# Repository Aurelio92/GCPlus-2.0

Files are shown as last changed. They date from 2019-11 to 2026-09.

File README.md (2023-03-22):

# GC+ - What is it?
GC+ is a custom board that acts as a Gamecube controller with an upgradable firmware and custom features.
Video reference: https://www.youtube.com/watch?v=MTG2iqWmXx4

# What's new in version 2.0?
* Firmware completely written in C
* Complete controller functionality, including analog triggers and rumble
* Hardware emulation of the GC controller protocol
* Includes a rumble motor driver that supports both LRA and ERM rumble motors
* Additional Z2/ZL button to be used as an extra input for the BT emulation hack
* Compatible with 3DS sliders/Switch sticks without an external converter
* Configurable via homebrew with customizations including:
    * Remappable buttons (except triggers) (via PMv2, coming soon!)
    * Configurable triggers mode between digital and analog, allowing to use both standard triggers and dual---action tacts
    * Completely reconfigurable sticks, both in terms of ranges, and relocation
    * A new deadzone mode allowing for smooth transition across the center of the sticks
* Completely upgradeable!

# How to make one?
Eagle files are available in the Hardware folder. Use them to order PCBs from your favourite manufacturer.

# Needed parts
A BOM is available in the Hardware folder

# How to compile it
GC+2.0 is split in two MPLAB IDE projects. All that you need to do is open GCPlus2.0_Bootloader.X in MPLAB IDE and compile it. GCPlus2.0_Bootloader loads GCPlus2.0 internally. This means that when you compile the bootloader, an unified hex file containing both the bootloader and the main payload firmware. The main firmware project is configured to use a different memory region to avoid overlaps with the bootloader.

# How to flash it
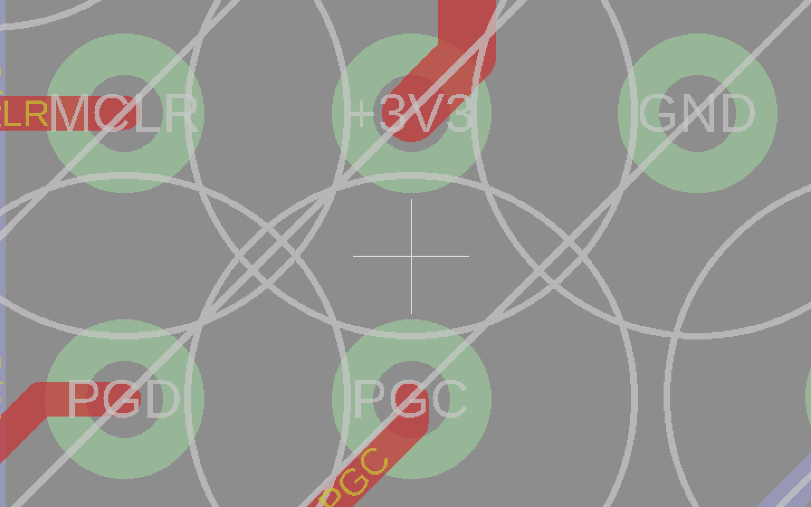
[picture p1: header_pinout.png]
picture alt
Markup : 
Flash GC+2.0.hex with MPLAB IPE (http://microchip.wikidot.com/ipe:installation) and a PICKIT v3 (or above).
Use the above pinout to wire up GC+2.0 to your PICKIT.

# Contacts
Please if you have any questions or if you want to implement new features reach out to me (Aurelio) on BitBuilt.net forums or our Discord server at https://discordapp.com/invite/uwT2AC.

If you use GC+2.0 and/or integrate it in your own project please do not forget to give credits where due and link to this repository.

# License

MIT License

Copyright (c) 2020 Aurelio Mannara

Permission is hereby granted, free of charge, to any person obtaining a copy
of this software and associated documentation files (the "Software"), to deal
in the Software without restriction, including without limitation the rights
to use, copy, modify, merge, publish, distribute, sublicense, and/or sell
copies of the Software, and to permit persons to whom the Software is
furnished to do so, subject to the following conditions:

The above copyright notice and this permission notice shall be included in all
copies or substantial portions of the Software.

THE SOFTWARE IS PROVIDED "AS IS", WITHOUT WARRANTY OF ANY KIND, EXPRESS OR
IMPLIED, INCLUDING BUT NOT LIMITED TO THE WARRANTIES OF MERCHANTABILITY,
FITNESS FOR A PARTICULAR PURPOSE AND NONINFRINGEMENT. IN NO EVENT SHALL THE
AUTHORS OR COPYRIGHT HOLDERS BE LIABLE FOR ANY CLAIM, DAMAGES OR OTHER
LIABILITY, WHETHER IN AN ACTION OF CONTRACT, TORT OR OTHERWISE, ARISING FROM,
OUT OF OR IN CONNECTION WITH THE SOFTWARE OR THE USE OR OTHER DEALINGS IN THE
SOFTWARE.E, ARISING FROM,
OUT OF OR IN CONNECTION WITH THE SOFTWARE OR THE USE OR OTHER DEALINGS IN THE
SOFTWARE.

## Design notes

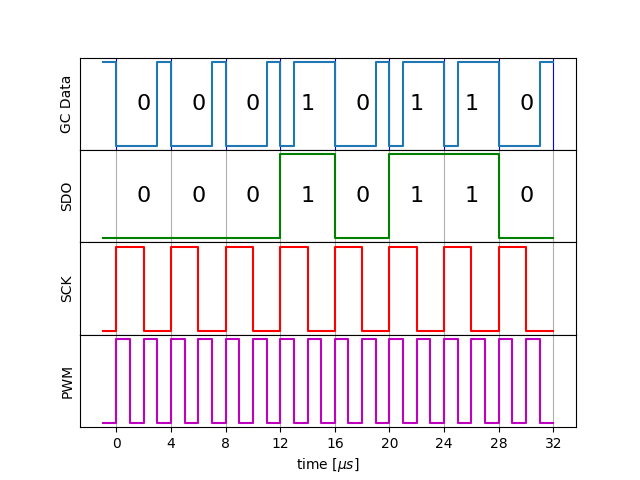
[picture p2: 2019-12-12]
gcplus2.png

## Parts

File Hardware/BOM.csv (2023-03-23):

Qty | Value | Device | Package | Parts | Description
3 | 0.1uF | C-EUC0402 | C0402 | C1, C2, C3 | CAPACITOR, European symbol
2 | 10kOhm | R-US_R0402 | R0402 | R1, R3 | RESISTOR, American symbol
1 | 100Ohm | R-US_R0402 | R0402 | R2 | RESISTOR, American symbol
1 | PIC18F25K42 | PIC18F25K42 | QFN-28 | U1
1 | DRV2603 | DRV2603 | WQFN-10 | U2

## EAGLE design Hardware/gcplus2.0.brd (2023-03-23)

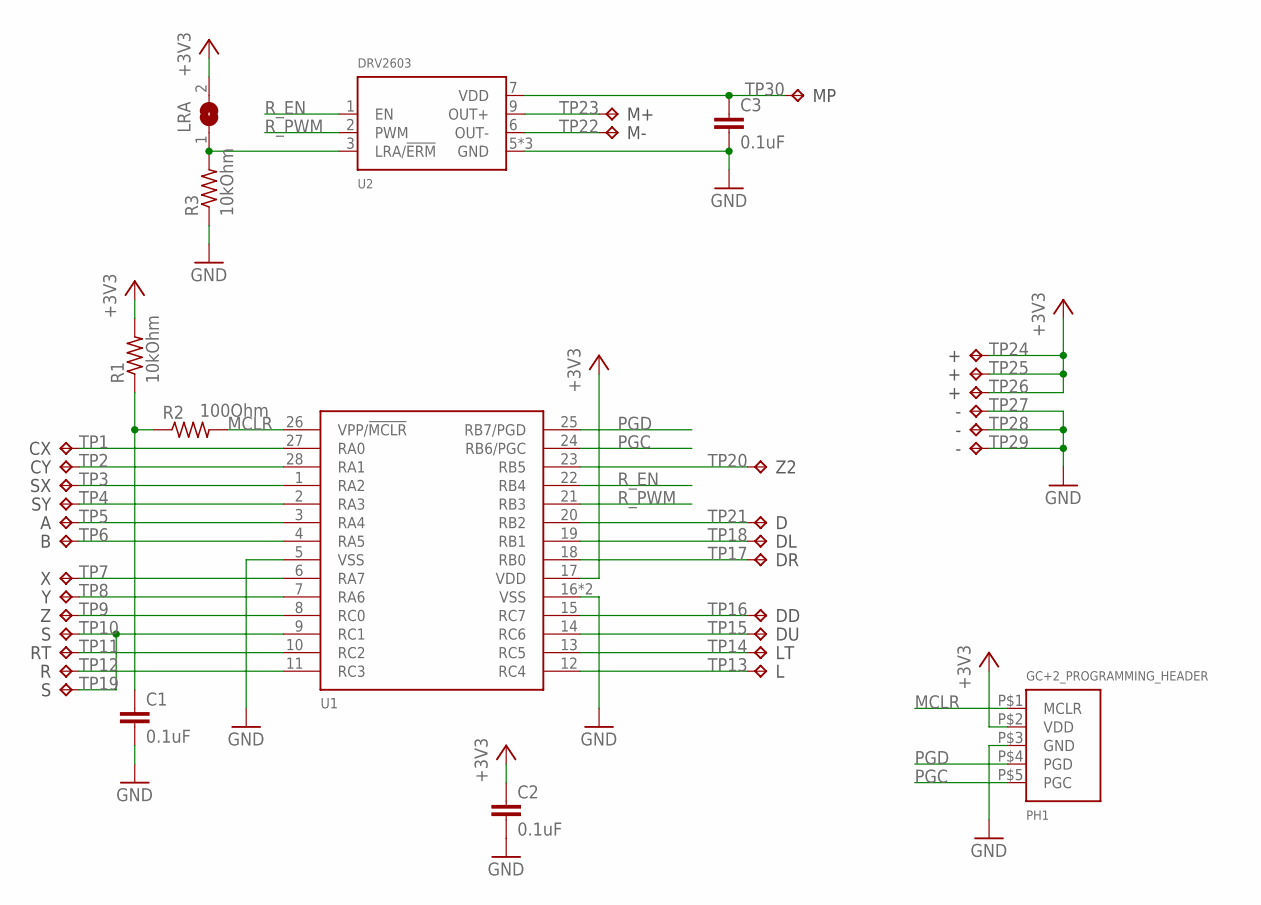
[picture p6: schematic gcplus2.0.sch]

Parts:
C1, C2, C3: 0.1uF; C0402
LRA: SJ
PH1: GC+2_PROGRAMMING_HEADER
R1, R3: 10kOhm; R0402
R2: 100Ohm; R0402
TP1, TP2, TP3, TP4, TP5, TP6, TP7, TP8, TP9, TP10, TP11, TP12, TP13, TP14, TP15, TP16, TP17, TP18, TP19, TP20, TP21, TP22, TP23, TP24, TP25, TP26, TP27, TP28, TP29, TP30: TPTP10SQ; TP10SQ
U1: PIC18F25K42; QFN-28
U2: DRV2603; WQFN-10

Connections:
+3V3: C2.1, LRA.2, PH1.P$2 (VDD), R1.2, TP24.TP, TP25.TP, TP26.TP, U1.17 (VDD)
GND: C1.2, C2.2, C3.2, PH1.P$3 (GND), R3.1, TP27.TP, TP28.TP, TP29.TP, U1.5 (VSS), U1.16 (VSS), U1.PAD (VSS), U2.5 (GND), U2.8 (GND), U2.10 (GND)
MCLR: PH1.P$1 (MCLR), R2.2, U1.26 (VPP/!MCLR)
MP: C3.1, TP30.TP, U2.7 (VDD)
unnamed: TP1.TP, U1.27 (RA0)
unnamed: TP2.TP, U1.28 (RA1)
unnamed: TP3.TP, U1.1 (RA2)
unnamed: TP4.TP, U1.2 (RA3)
unnamed: TP5.TP, U1.3 (RA4)
unnamed: TP6.TP, U1.4 (RA5)
unnamed: TP7.TP, U1.6 (RA7)
unnamed: TP8.TP, U1.7 (RA6)
unnamed: TP9.TP, U1.8 (RC0)
unnamed: LRA.1, R3.2, U2.3 (LRA/!ERM)
unnamed: TP10.TP, TP19.TP, U1.9 (RC1)
unnamed: TP11.TP, U1.10 (RC2)
unnamed: TP12.TP, U1.11 (RC3)
unnamed: TP14.TP, U1.13 (RC5)
unnamed: TP15.TP, U1.14 (RC6)
unnamed: TP16.TP, U1.15 (RC7)
unnamed: TP17.TP, U1.18 (RB0)
unnamed: TP18.TP, U1.19 (RB1)
unnamed: TP21.TP, U1.20 (RB2)
unnamed: TP23.TP, U2.9 (OUT+)
unnamed: TP22.TP, U2.6 (OUT-)
unnamed: TP20.TP, U1.23 (RB5)
unnamed: C1.1, R1.1, R2.1
unnamed: TP13.TP, U1.12 (RC4)
PGC: PH1.P$5 (PGC), U1.24 (RB6/PGC)
PGD: PH1.P$4 (PGD), U1.25 (RB7/PGD)
R_EN: U1.22 (RB4), U2.1 (EN)
R_PWM: U1.21 (RB3), U2.2 (PWM)

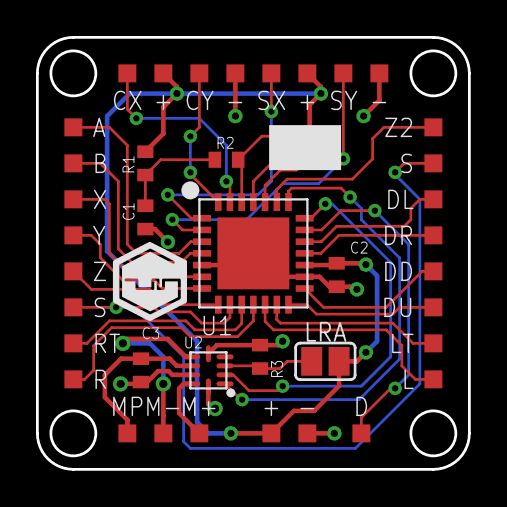
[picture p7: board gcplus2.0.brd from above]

Board: 2 copper layers, 24.0 x 24.0 mm, 40 parts (0 on the bottom side), 32 nets.

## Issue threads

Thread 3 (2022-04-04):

Usar potenciómetros xbox como gatitos L R

JackLine087, 2022-04-04:
Hola soy nuevo con esta placa GC Plus y quería hacer un proyecto de usar un control de Xbox clásico del primer control, mi idea es usar el gc plus como el cerebro del control sería como añadir un nuevo núcleo que remapearia los botones de la placa del control al gc plus eso es fácil solo soldando unos cables internos que no ocupan mayor espacio, y ejecutarlo como si fuera un control de gamecube no obstante, tengo una duda y es que los controles de xbox clássico en los gatillo (L R) no poseen botones sino que usa potenciómetros y queria saber como podría ejecutar estos potenciómetros como botones para el gc plus 🙏

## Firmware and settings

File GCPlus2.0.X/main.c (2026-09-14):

// CONFIG1L
#pragma config FEXTOSC = OFF    // External Oscillator Selection (Oscillator not enabled)
#pragma config RSTOSC = HFINTOSC_64MHZ// Reset Oscillator Selection (HFINTOSC with HFFRQ = 64 MHz and CDIV = 1:1)

// CONFIG1H
#pragma config CLKOUTEN = OFF   // Clock out Enable bit (CLKOUT function is disabled)
#pragma config PR1WAY = OFF     // PRLOCKED One-Way Set Enable bit (PRLOCK bit can be set and cleared repeatedly)
#pragma config CSWEN = ON       // Clock Switch Enable bit (Writing to NOSC and NDIV is allowed)
#pragma config FCMEN = ON       // Fail-Safe Clock Monitor Enable bit (Fail-Safe Clock Monitor enabled)

// CONFIG2L
#pragma config MCLRE = EXTMCLR  // MCLR Enable bit (If LVP = 0, MCLR pin is MCLR; If LVP = 1, RE3 pin function is MCLR )
#pragma config PWRTS = PWRT_OFF // Power-up timer selection bits (PWRT is disabled)
#pragma config MVECEN = OFF     // Multi-vector enable bit (Interrupt contoller does not use vector table to prioritze interrupts)
#pragma config IVT1WAY = OFF    // IVTLOCK bit One-way set enable bit (IVTLOCK bit can be cleared and set repeatedly)
#pragma config LPBOREN = OFF    // Low Power BOR Enable bit (ULPBOR disabled)
#pragma config BOREN = SBORDIS  // Brown-out Reset Enable bits (Brown-out Reset enabled , SBOREN bit is ignored)

// CONFIG2H
#pragma config BORV = VBOR_2P85 // Brown-out Reset Voltage Selection bits (Brown-out Reset Voltage (VBOR) set to 2.85V)
#pragma config ZCD = OFF        // ZCD Disable bit (ZCD disabled. ZCD can be enabled by setting the ZCDSEN bit of ZCDCON)
#pragma config PPS1WAY = OFF    // PPSLOCK bit One-Way Set Enable bit (PPSLOCK bit can be set and cleared repeatedly (subject to the unlock sequence))
#pragma config STVREN = ON      // Stack Full/Underflow Reset Enable bit (Stack full/underflow will cause Reset)
#pragma config DEBUG = OFF      // Debugger Enable bit (Background debugger disabled)
#pragma config XINST = OFF      // Extended Instruction Set Enable bit (Extended Instruction Set and Indexed Addressing Mode disabled)

// CONFIG3L
#pragma config WDTCPS = WDTCPS_12// WDT Period selection bits (Divider ratio 1:131072)
#pragma config WDTE = ON        // WDT operating mode (WDT enabled regardless of sleep)

// CONFIG3H
#pragma config WDTCWS = WDTCWS_7// WDT Window Select bits (window always open (100%); software control; keyed access not required)
#pragma config WDTCCS = LFINTOSC// WDT input clock selector (WDT reference clock is the 31.0 kHz LFINTOSC)

// CONFIG4L
#pragma config BBSIZE = BBSIZE_4096// Boot Block Size selection bits (Boot Block size is 4096 words)
#pragma config BBEN = ON       // Boot Block enable bit (Boot block enabled)
#pragma config SAFEN = ON       // Storage Area Flash enable bit (SAF enabled)
#pragma config WRTAPP = OFF     // Application Block write protection bit (Application Block not write protected)

// CONFIG4H
#pragma config WRTB = ON        // Configuration Register Write Protection bit (Configuration registers (300000-30000Bh) write-protected)
#pragma config WRTC = OFF       // Boot Block Write Protection bit (Boot Block (000000-0007FFh) not write-protected)
#pragma config WRTD = OFF       // Data EEPROM Write Protection bit (Data EEPROM not write-protected)
#pragma config WRTSAF = OFF     // SAF Write protection bit (SAF not Write Protected)
#pragma config LVP = ON         // Low Voltage Programming Enable bit (Low voltage programming enabled. MCLR/VPP pin function is MCLR. MCLRE configuration bit is ignored)

// CONFIG5L
#pragma config CP = OFF         // PFM and Data EEPROM Code Protection bit (PFM and Data EEPROM code protection disabled)

#include "main.h"

void main(void) {
    uint8_t i;
    uint8_t cmdLen = 0;
    char cmd[0x24];
    char msgAnswer[0x24];
    uint8_t gcpLocked = 1;
    uint16_t addr;

    //Bootloader buffer stuff
    uint8_t flashBuffer[64];
    uint8_t flashBufferIdx = 0;

    /*//Clock is already be set at 64MHz in the configuration register. This is useless
    // NOSC HFINTOSC; NDIV 1;
    OSCCON1 = 0x60;
    // CSWHOLD may proceed; SOSCPWR Low power;
    OSCCON3 = 0x00;
    // MFOEN disabled; LFOEN disabled; ADOEN disabled; SOSCEN disabled; EXTOEN disabled; HFOEN disabled;
    OSCEN = 0x00;
    // HFFRQ 64_MHz;
    OSCFRQ = 0x08;
    // TUN 0;
    OSCTUNE = 0x00;*/

    portsInit();

    //Read buttons for boot combos
    inButtons_t inBut;
    inBut.PORTA = PORTA;
    inBut.PORTB = PORTB;
    inBut.PORTC = PORTC;

    configInit();
    if (config.triggersMode == TRIG_MODE_ANALOG) {
        ANSELC |= 0x18; //Enable analog on triggers
        WPUC &= ~0x18; //Disable weak pullups on triggers
    }

    ADCInit(config.SXChan, config.SYChan, config.CXChan, config.CYChan);
    buttonsInit();
    SIInit();
    rumbleInit();
    //Restore configuration if X+Y+A are all pressed
    if (!inBut.X && !inBut.Y && !inBut.A) {
        configSetDefault();
        configFlashAll();
    }

    buttonsBuildLUTs();

    INTCON0 = 0x80; //Interrupts enabled with no priority

    while (1) {
        inBut.PORTA = PORTA;
        inBut.PORTB = PORTB;
        inBut.PORTC = PORTC;
        //If X+Y+Start are all pressed, don't reset the WDT
        if (inBut.X || inBut.Y || inBut.ST) {
            asm("clrwdt");
        }
        buttonsUpdate();
        cmdLen = SIGetCommand(cmd);

        if (cmdLen > 0) {
            switch(cmd[0]) {
                case GCP_CMD_LOCKUNLOCK:
                    if ((cmd[1] == 0x47) && (cmd[2] == 0x43) && (cmd[3] == 0x2B) && (cmd[4] == 0x32) && cmdLen == 5) {
                        gcpLocked = 0;
                    } else {
                        gcpLocked = 1;
                    }
                    msgAnswer[0] = GCP_ERR_NONE;
                    SISendMessage(msgAnswer, 1);
                break;

                case GCP_CMD_GETVER:
                    if (!gcpLocked) {
                        msgAnswer[0] = 0x02; //Payload
                        msgAnswer[1] = GCP2_VERSION & 0xFFUL;
                        msgAnswer[2] = (GCP2_VERSION >> 8) & 0xFF;
                        msgAnswer[3] = GCP2_HWVERSION & 0xFFUL;
                        msgAnswer[4] = (GCP2_HWVERSION >> 8) & 0xFF;
                        SISendMessage(msgAnswer, 5);
                    } else {
                        msgAnswer[0] = GCP_ERR_LOCKED;
                        SISendMessage(msgAnswer, 1);
                    }
                break;

                case GCP_CMD_WRITEEEPROM:
                    if (!gcpLocked) {
                        if (cmdLen > 3) {
                            addr = cmd[2];
                            addr = addr << 8;
                            addr |= cmd[1];
                            for (i = 3; i < cmdLen; i++) {
                                EEPROMWriteByte(addr++, cmd[i]);
                            }
                            msgAnswer[0] = GCP_ERR_NONE;
                            SISendMessage(msgAnswer, 1);
                        } else {
                            msgAnswer[0] = GCP_ERR_WRONGARG;
                            SISendMessage(msgAnswer, 1);
                        }
                    } else {
                        msgAnswer[0] = GCP_ERR_LOCKED;
                        SISendMessage(msgAnswer, 1);
                    }
                break;

                case GCP_CMD_READEEPROM:
                    if (!gcpLocked) {
                        if (cmdLen == 4) {
                            addr = cmd[2];
                            addr = addr << 8;
                            addr |= cmd[1];
                            uint8_t len = cmd[3];
                            if (len == 0) {
                                msgAnswer[0] = GCP_ERR_WRONGARG;
                                SISendMessage(msgAnswer, 1);
                            } else {
                                msgAnswer[0] = GCP_ERR_NONE;
                                for (i = 0; i < len && i < 0x20; i++) {
                                    msgAnswer[i + 1] = EEPROMReadByte(addr++);
                                }
                                SISendMessage(msgAnswer, len + 1);
                            }
                        } else {
                            msgAnswer[0] = GCP_ERR_WRONGARG;
                            SISendMessage(msgAnswer, 1);
                        }
                    } else {
                        msgAnswer[0] = GCP_ERR_LOCKED;
                        SISendMessage(msgAnswer, 1);
                    }
                break;

                case GCP_CMD_RESET:
                    asm("reset");
                break;

                case GCP_CMD_BOOTBL:
                    if (!gcpLocked) {
                        msgAnswer[0] = GCP_ERR_NONE;
                        SISendMessage(msgAnswer, 1);
                        bootBootloader();
                    } else {
                        msgAnswer[0] = GCP_ERR_LOCKED;
                        SISendMessage(msgAnswer, 1);
                    }
                break;

                case GCP_CMD_SETMAPBYTE0:
                    if (!gcpLocked) {
                        if (cmdLen == (N_BUTTONS + 1)) {
                            buttonsSetMapByte0(&cmd[1]);
                            msgAnswer[0] = GCP_ERR_NONE;
                            SISendMessage(msgAnswer, 1);
                        } else {
                            msgAnswer[0] = GCP_ERR_WRONGARG;
                            SISendMessage(msgAnswer, 1);
                        }
                    } else {
                        msgAnswer[0] = GCP_ERR_LOCKED;
                        SISendMessage(msgAnswer, 1);
                    }
                break;

                case GCP_CMD_SETMAPBYTE1:
                    if (!gcpLocked) {
                        if (cmdLen == (N_BUTTONS + 1)) {
                            buttonsSetMapByte1(&cmd[1]);
                            msgAnswer[0] = GCP_ERR_NONE;
                            SISendMessage(msgAnswer, 1);
                        } else {
                            msgAnswer[0] = GCP_ERR_WRONGARG;
                            SISendMessage(msgAnswer, 1);
                        }
                    } else {
                        msgAnswer[0] = GCP_ERR_LOCKED;
                        SISendMessage(msgAnswer, 1);
                    }
                break;

                case GCP_CMD_GETMAPBYTE0:
                    if (!gcpLocked) {
                        uint8_t* btnMsg = buttonsGetMapByte0();
                        msgAnswer[0] = GCP_ERR_NONE;
                        for (i = 0; i < N_BUTTONS; i++) {
                            msgAnswer[i + 1] = btnMsg[i];
                        }
                        SISendMessage(msgAnswer, N_BUTTONS + 1);
                    } else {
                        msgAnswer[0] = GCP_ERR_LOCKED;
                        SISendMessage(msgAnswer, 1);
                    }
                break;

                case GCP_CMD_GETMAPBYTE1:
                    if (!gcpLocked) {
                        uint8_t* btnMsg = buttonsGetMapByte1();
                        msgAnswer[0] = GCP_ERR_NONE;
                        for (i = 0; i < N_BUTTONS; i++) {
                            msgAnswer[i + 1] = btnMsg[i];
                        }
                        SISendMessage(msgAnswer, N_BUTTONS + 1);
                    } else {
                        msgAnswer[0] = GCP_ERR_LOCKED;
                        SISendMessage(msgAnswer, 1);
                    }
                break;

                case GCP_CMD_REBUILDLUT:
                    if (!gcpLocked) {
                        buttonsBuildLUTs();
                        msgAnswer[0] = GCP_ERR_NONE;
                        SISendMessage(msgAnswer, 1);
                    } else {
                        msgAnswer[0] = GCP_ERR_LOCKED;
                        SISendMessage(msgAnswer, 1);
                    }
                break;

                default: //Unknown command
                    SIClear();
                break;
            }
        }
    }

    return;
}

//Commands answered at their stop bit. Called from the interrupt handler
static uint8_t idAnswer[3] = {0x09, 0x00, 0x03};
static uint8_t originAnswer[10] = {0x00, 0x80, 0x80, 0x80, 0x80, 0x80, 0x00, 0x00, 0x00, 0x00};

uint8_t directCommandLength(uint8_t cmd) {
    switch(cmd) {
        case SI_CMD_ID:
        case SI_CMD_RESET:
        case SI_CMD_ORIGINS:
            return 1;

        case SI_CMD_POLL:
        case SI_CMD_CALIB:
            return 3;

        default: //Not answered from the interrupt handler. Handled by the main loop after the bus timeout
            return 0;
    }
}

void directCommandAnswer(uint8_t* cmd) {
    switch(cmd[0]) {
        case SI_CMD_ID:
        case SI_CMD_RESET:
            SISendMessage(idAnswer, 3);
        break;

        case SI_CMD_POLL:
            //Handle rumble
            switch (cmd[2]) {
                case 1:
                    rumbleSpin(config.rumbleIntensity);
                break;

                case 2:
                    rumbleBrake();
                break;

                default:
                    rumbleStop();
                break;
            }
            //Answer
            SISendMessage(buttonsGetMessage(cmd[1], config.triggersMode), 8);
        break;

        case SI_CMD_ORIGINS:
        case SI_CMD_CALIB:
            SISendMessage(originAnswer, 10);
        break;
    }
}

void portsInit(void) {
    //Stop interrupts
    bool state = (unsigned char)GIE;
    GIE = 0;
    PPSLOCK = 0x55;
    PPSLOCK = 0xAA;
    PPSLOCKbits.PPSLOCKED = 0x00; //Unlock PPS

    //Data line wired to RB2
    //Reception
    T6INPPS = 0x0A; //RB2 to T6INPPS. Used as reset trigger
    SMT1SIGPPS = 0x0A; //RB2

    //Transmission
    RB2PPS = 0x04; //CLC4 to RB2

    //Rumble PWM
    RB3PPS = 0x09; //CCP1

    PPSLOCK = 0x55;
    PPSLOCK = 0xAA;
    PPSLOCKbits.PPSLOCKED = 0x01; //Lock PPS
    GIE = state; //Restore interrupts

    LATB = 0xEF;

    //Bootloader won't emulate analog triggers
    TRISA = 0xFF;
    TRISB = 0xE7;
    TRISC = 0xFF;
    ANSELA = 0x0F;
    ANSELB = 0x00;
    ANSELC = 0x00;
    WPUA = 0xF0;
    WPUB = 0x27;
    WPUC = 0xFF;
    ODCONA = 0x00;
    ODCONB = 0x04;
    ODCONC = 0x00;
}

void bootBootloader(void) {
    INTCON0 = 0x00; //Disable interrupts
    NCO1ACCL = 0x01;
    STKPTR = 0x00; //Clean up stack
    IVTLOCK = 0x55;
    IVTLOCK = 0xAA;
    IVTLOCK = 0;
    IVTLOCKED = 0;
    IVTBASE = 8; //Set interrupt base address
    IVTLOCK = 0x55;
    IVTLOCK = 0xAA;
    IVTLOCK = 1;
    IVTLOCKED = 1;
    //Jump to bootloader
    PCLATU = 0x00;
    PCLATH = 0x00;
    PCL = 0x00;
}

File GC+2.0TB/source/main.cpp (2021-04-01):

#include <stdio.h>
#include <stdlib.h>
#include <string.h>
#include <gccore.h>
#include <ogc/lwp_watchdog.h>
#include <ogc/machine/processor.h>
#include <wiiuse/wpad.h>
#include <ogc/ipc.h>
#include <fat.h>
#include <math.h>
#include <string>
#include <list>

#include "gpio.h"
#include "i2c.h"
#include "gcplus.h"

static void *xfb = NULL;
static GXRModeObj *rmode = NULL;

#define AVE_ADDR (0x70 << 1)

void startTest();
void padWait(int* held);
void printButtons(int held);
void testStickAxis(int ax);

std::list<std::string> errorList;

//---------------------------------------------------------------------------------
int main(int argc, char **argv) {
//---------------------------------------------------------------------------------

	// Initialise the video system
	VIDEO_Init();
	PAD_Init();
	WPAD_Init();

	// Obtain the preferred video mode from the system
	// This will correspond to the settings in the Wii menu
	rmode = VIDEO_GetPreferredMode(NULL);

	// Allocate memory for the display in the uncached region
	xfb = MEM_K0_TO_K1(SYS_AllocateFramebuffer(rmode));

	// Initialise the console, required for printf
	console_init(xfb,20,20,rmode->fbWidth,rmode->xfbHeight,rmode->fbWidth*VI_DISPLAY_PIX_SZ);

	// Set up the video registers with the chosen mode
	VIDEO_Configure(rmode);

	// Tell the video hardware where our display memory is
	VIDEO_SetNextFramebuffer(xfb);

	// Make the display visible
	VIDEO_SetBlack(FALSE);

	// Flush the video register changes to the hardware
	VIDEO_Flush();

	// Wait for Video setup to complete
	VIDEO_WaitVSync();
	if(rmode->viTVMode&VI_NON_INTERLACE) VIDEO_WaitVSync();

	int col, row;
	CON_GetPosition(&col, &row);

	u8 error;

	i2c_init();
	printf("\n\n");
	i2c_stop();

	for (int i = 0; i < 127; i++)
	{
		i2c_start();
		if (i2c_sendByte(i << 1))
		{
			printf("Found device on address: %02X\n", i);
		}
		i2c_stop();
	}

	printf("SI type: %08X\n", SI_GetType(0));
	printf("Press A on the Wiimote to start the test\n");
	while(1) {
		PAD_ScanPads();
		WPAD_ScanPads();


		int down = WPAD_ButtonsDown(0);
		if (down & WPAD_BUTTON_HOME) exit(0);
		if (down & WPAD_BUTTON_A) startTest();

		int held = PAD_ButtonsHeld(0);

		/*if (ticks_to_millisecs(gettime() - now) > 1000) {
			regVal = ~regVal;
			i2c_write8(0x40, 0x01, regVal, &error);
			now = gettime();
		}

		printf("\x1b[5;0H%08X %02X", held, regVal);*/

		// Wait for the next frame
		VIDEO_WaitVSync();
	}

	return 0;
}

void padWait(int* held) {
	u64 now = gettime();
	while (ticks_to_millisecs(gettime() - now) < 200) {
		PAD_ScanPads();
	}
	if (held != NULL) *held = PAD_ButtonsHeld(0);
}

void printButtons(int held) {
	if (held & PAD_BUTTON_A) printf("A ");
	if (held & PAD_BUTTON_B) printf("B ");
	if (held & PAD_BUTTON_X) printf("X ");
	if (held & PAD_BUTTON_Y) printf("Y ");
	if (held & PAD_TRIGGER_Z) printf("Z ");
	if (held & PAD_TRIGGER_R) printf("RT ");
	if (held & PAD_TRIGGER_L) printf("LT ");
	if (held & PAD_BUTTON_START) printf("START ");
	if (held & PAD_BUTTON_LEFT) printf("LEFT ");
	if (held & PAD_BUTTON_RIGHT) printf("RIGHT ");
	if (held & PAD_BUTTON_DOWN) printf("DOWN ");
	if (held & PAD_BUTTON_UP) printf("UP ");
	if (PAD_StickX(0)) printf("SX(%d) ", PAD_StickX(0));
	if (PAD_StickY(0)) printf("SY(%d) ", PAD_StickY(0));
	if (PAD_SubStickX(0)) printf("CX(%d) ", PAD_SubStickX(0));
	if (PAD_SubStickY(0)) printf("CY(%d) ", PAD_SubStickY(0));
	if (PAD_TriggerL(0)) printf("L(%u) ", PAD_TriggerL(0));
	if (PAD_TriggerR(0)) printf("R(%u) ", PAD_TriggerR(0));
}

void printButtonsToString(int held, char* str) {
	if (held & PAD_BUTTON_A) sprintf(str, "%sA ", str);
	if (held & PAD_BUTTON_B) sprintf(str, "%sB ", str);
	if (held & PAD_BUTTON_X) sprintf(str, "%sX ", str);
	if (held & PAD_BUTTON_Y) sprintf(str, "%sY ", str);
	if (held & PAD_TRIGGER_Z) sprintf(str, "%sZ ", str);
	if (held & PAD_TRIGGER_R) sprintf(str, "%sRT ", str);
	if (held & PAD_TRIGGER_L) sprintf(str, "%sLT ", str);
	if (held & PAD_BUTTON_START) sprintf(str, "%sSTART ", str);
	if (held & PAD_BUTTON_LEFT) sprintf(str, "%sLEFT ", str);
	if (held & PAD_BUTTON_RIGHT) sprintf(str, "%sRIGHT ", str);
	if (held & PAD_BUTTON_DOWN) sprintf(str, "%sDOWN ", str);
	if (held & PAD_BUTTON_UP) sprintf(str, "%sUP ", str);
	if (PAD_StickX(0)) sprintf(str, "%sSX(%d) ", str, PAD_StickX(0));
	if (PAD_StickY(0)) sprintf(str, "%sSY(%d) ", str, PAD_StickY(0));
	if (PAD_SubStickX(0)) sprintf(str, "%sCX(%d) ", str, PAD_SubStickX(0));
	if (PAD_SubStickY(0)) sprintf(str, "%sCY(%d) ", str, PAD_SubStickY(0));
	if (PAD_TriggerL(0)) sprintf(str, "%sL(%u) ", str, PAD_TriggerL(0));
	if (PAD_TriggerR(0)) sprintf(str, "%sR(%u) ", str, PAD_TriggerR(0));
}

void testStickAxis(int ax) {
	u8 error;
	i2c_write8(0x40, 0x03, 0x80, &error); //SX
	i2c_write8(0x40, 0x04, 0x80, &error); //SY
	i2c_write8(0x40, 0x05, 0x80, &error); //CX
	i2c_write8(0x40, 0x06, 0x80, &error); //CY

	bool failed = false;

	for (int i = 0; i < 8; i++) {
		int stickVal;
		i2c_write8(0x40, 0x03 + ax, i << 5, &error);
		padWait(NULL);
		switch (ax) {
			case 0:
				stickVal = PAD_StickX(0) + 128;
			break;
			case 1:
				stickVal = PAD_StickY(0) + 128;
			break;
			case 2:
				stickVal = PAD_SubStickX(0) + 128;
			break;
			case 3:
				stickVal = PAD_SubStickY(0) + 128;
			break;
		}
		printf("Sent 0x%02X. Got 0x%02X\n", i << 5, stickVal);

		if (abs(stickVal - (i << 5)) > 32) {
			failed = true;
		}
	}

	if (failed) {
		switch (ax) {
			case 0:
				errorList.push_back("Error on SX");
			break;
			case 1:
				errorList.push_back("Error on SY");
			break;
			case 2:
				errorList.push_back("Error on CX");
			break;
			case 3:
				errorList.push_back("Error on CY");
			break;
		}
	}
}
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

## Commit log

2019-11-03 Implemented buttons mapping
2019-11-04 Fixed buttons mapping
2023-03-22 Version 2.3 Fixed issues with rumble
    [main.c]
2023-03-23 Added back Firmware and Hardware folders
    [BOM.csv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]
